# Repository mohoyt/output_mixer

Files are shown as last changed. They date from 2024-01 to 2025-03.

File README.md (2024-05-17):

# Output mixer for Eurorack

Inspired by the mixer in the Erica Synths x mki.edu line (but with added channels and SMD components)

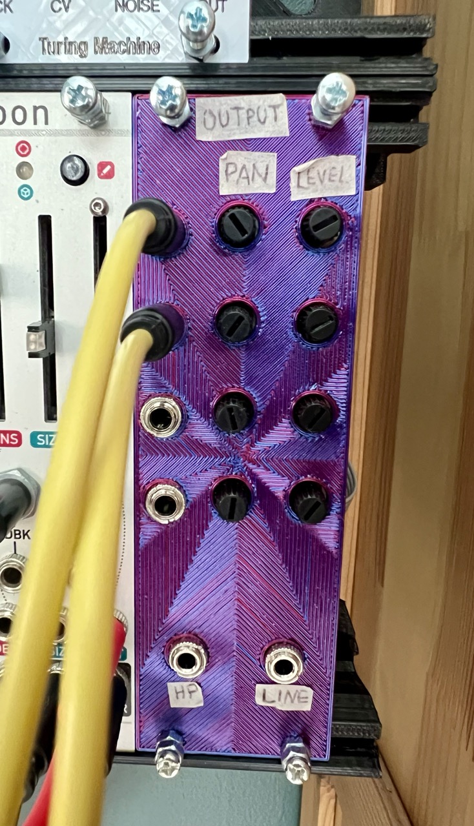
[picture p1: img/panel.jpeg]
Panel


## Features
- Eurorack format (3U panel height = 133.4mm)
- 8HP width (about 40mm)
- 4 inputs with pan (L-R) and level adjustable
- 2 outputs, line out and headphone out
- Mostly SMD with a couple through hole parts

## Issues
- [x] Pan is reversed
- [x] Not enough space for 1W 47R resistor
- [x] BD139/140 overheating

All addressed in current version (v1.1). The overheating was a result of poor quality BD139 and BD140 that I had sourced. 

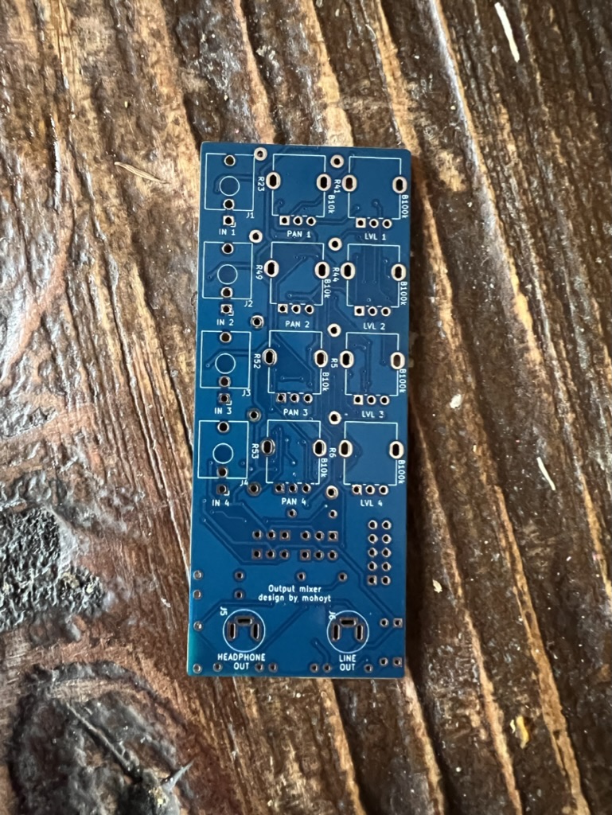
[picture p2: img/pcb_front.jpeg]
PCB front


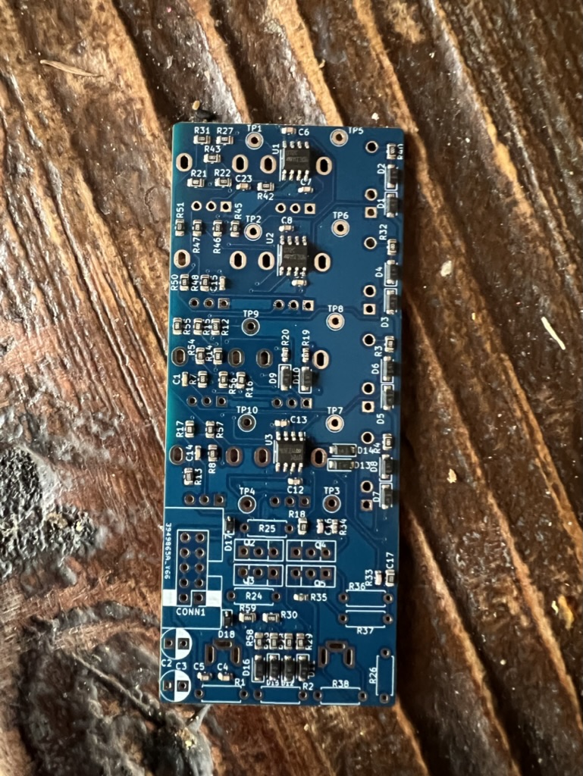
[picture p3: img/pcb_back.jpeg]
PCB back


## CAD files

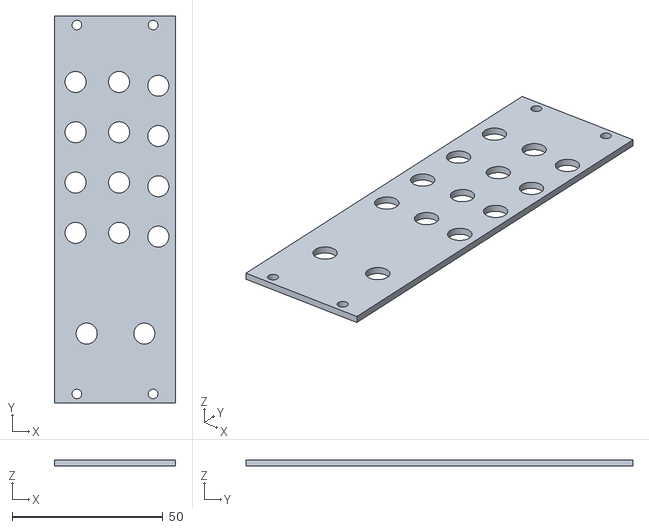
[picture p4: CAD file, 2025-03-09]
panel/Output Mixer.stl
40.3 x 128.5 x 2.00

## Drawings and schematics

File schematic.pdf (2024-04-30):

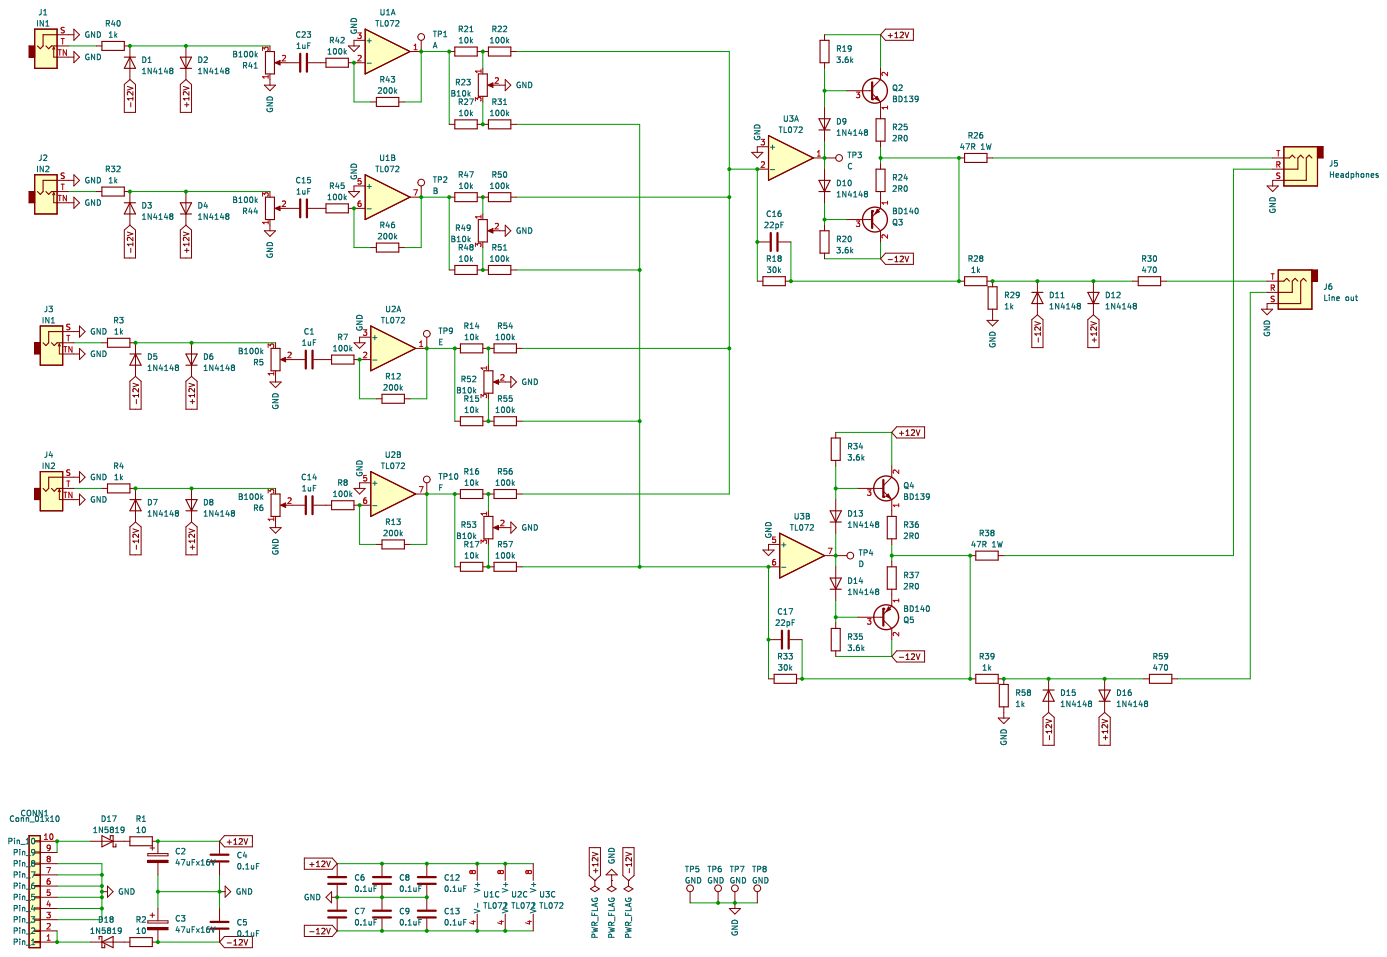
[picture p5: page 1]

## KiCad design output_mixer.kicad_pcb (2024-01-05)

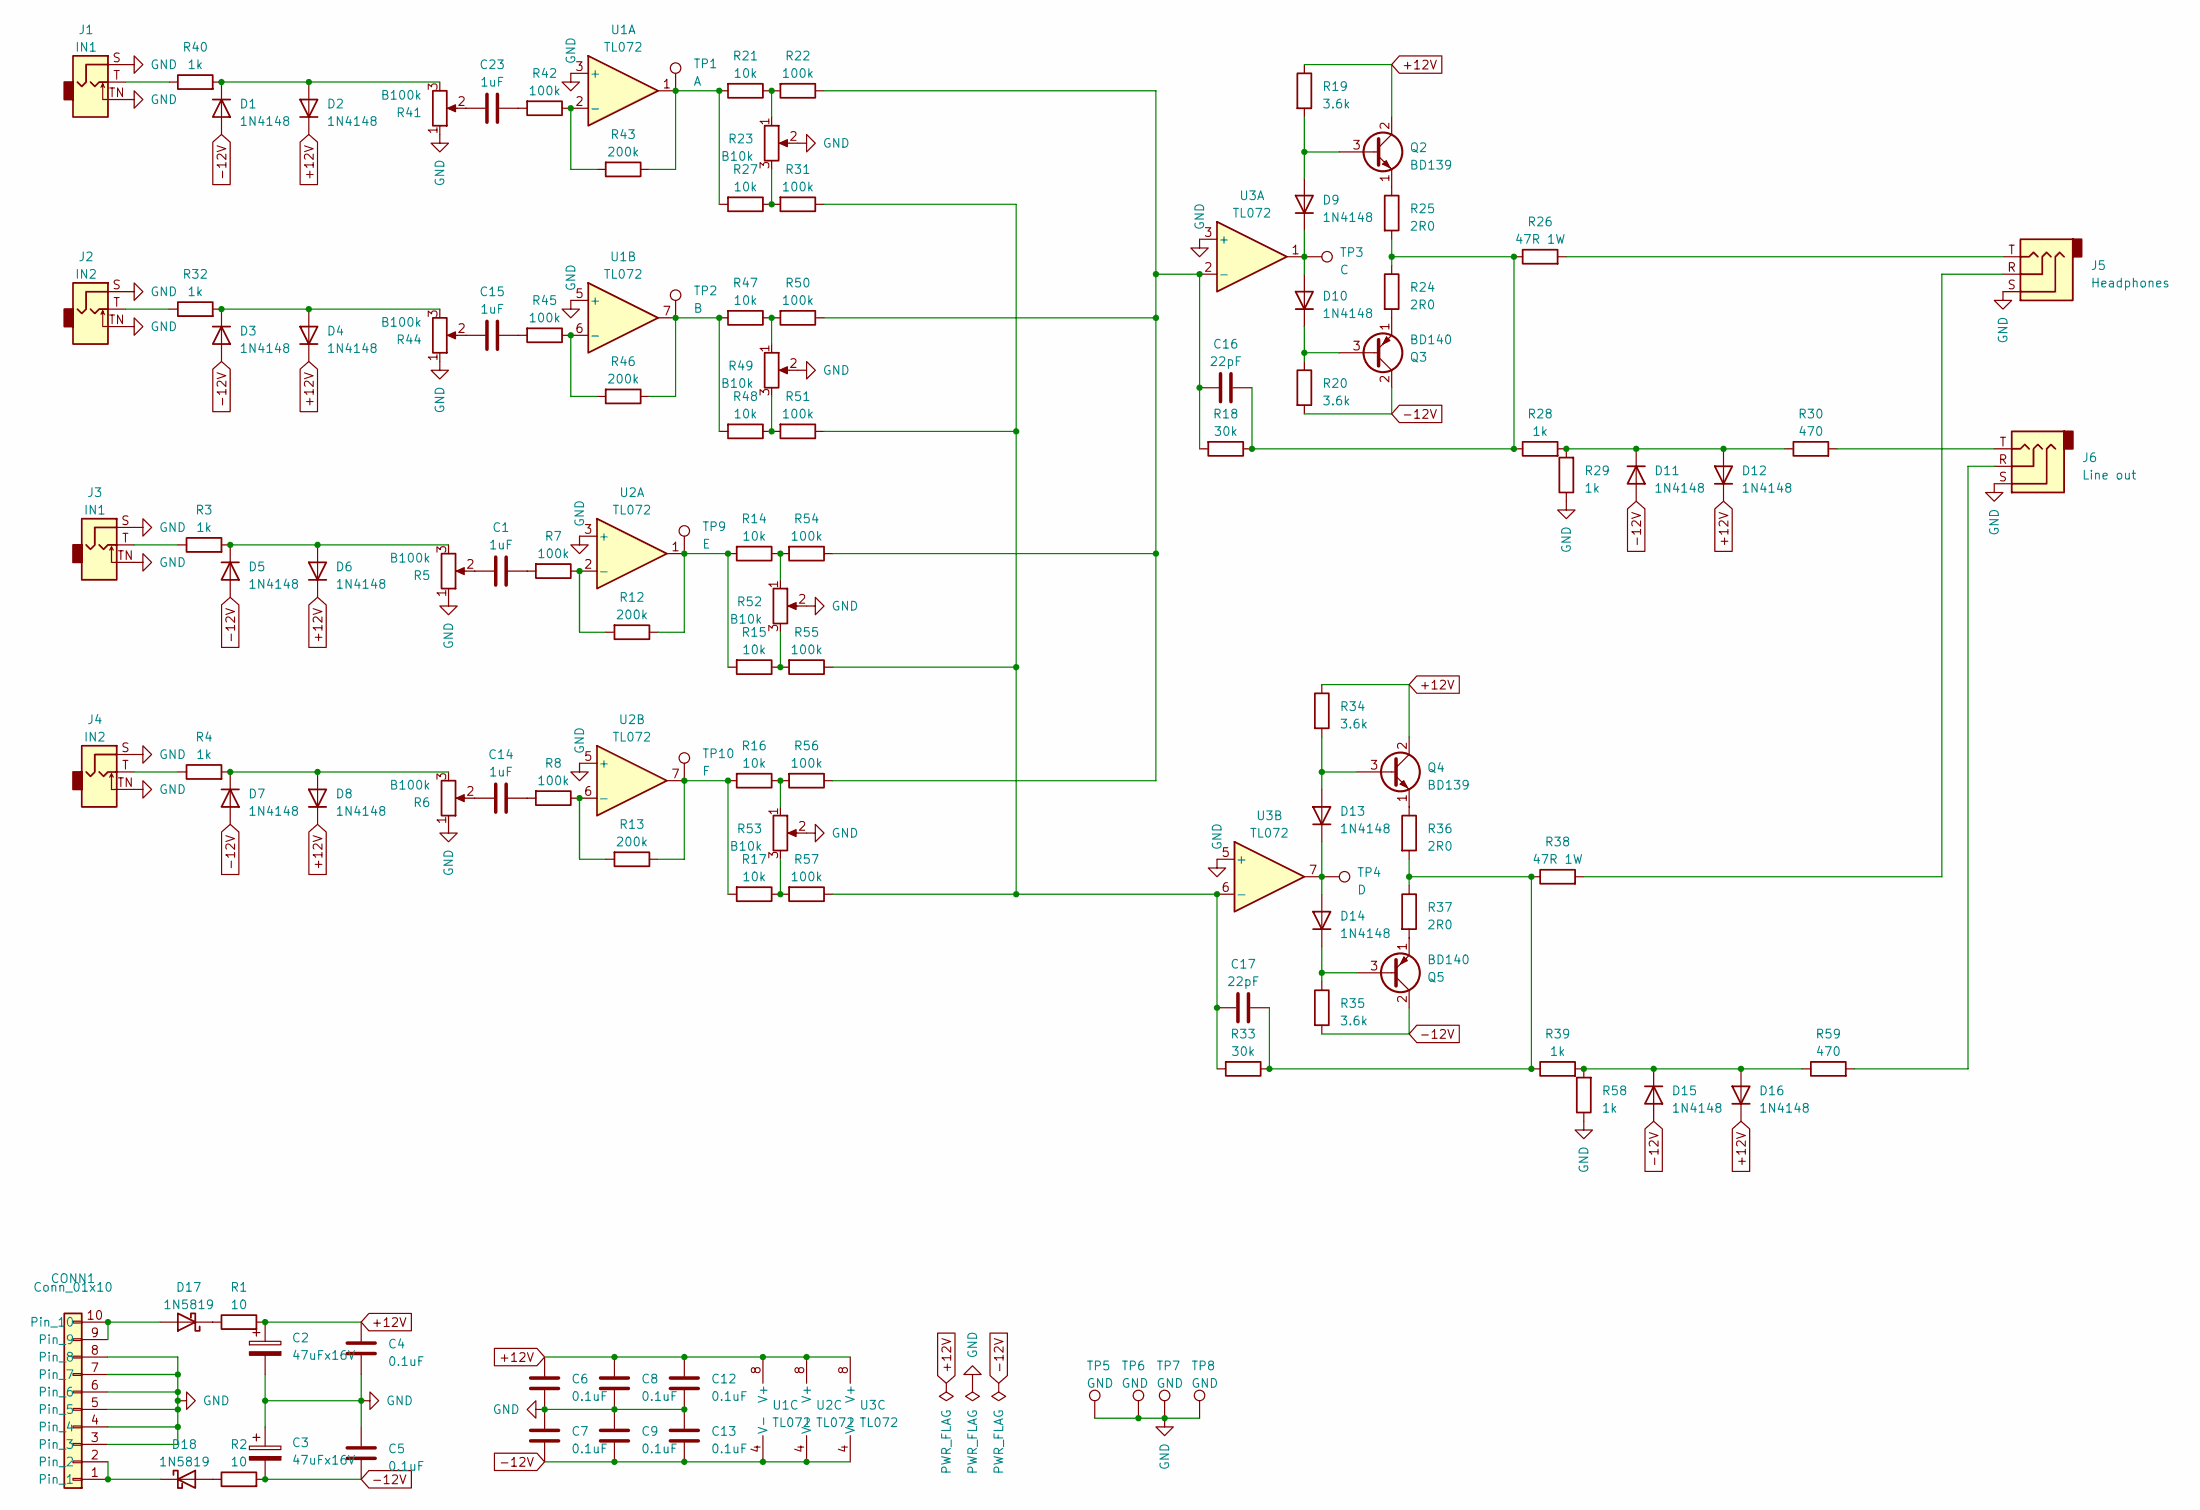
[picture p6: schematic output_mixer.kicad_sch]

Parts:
C1, C14, C15, C23: 1uF; C_0603_1608Metric; LCSC C15849
C2, C3: 47uFx16V; CP_Radial_D5.0mm_P2.50mm
C4, C5, C6, C7, C8, C9, C12, C13: 0.1uF; C_0603_1608Metric; LCSC C14663
C16, C17: 22pF; C_0603_1608Metric; LCSC C1653
CONN1: Conn_01x10; PinHeader_2x05_P2.54mm_Vertical_Shroud
D1, D2, D3, D4, D5, D6, D7, D8, D9, D10, D11, D12, D13, D14, D15, D16: 1N4148; D_SOD-123; LCSC C81598
D17, D18: 1N5819; D_SOD-323; LCSC C191023
J1, J3: IN1; Jack_3.5mm_QingPu_WQP-PJ398SM_Vertical_CircularHoles
J2, J4: IN2; Jack_3.5mm_QingPu_WQP-PJ398SM_Vertical_CircularHoles
J5: Headphones; Jack_3.5mm_Stereo_Unbranded
J6: Line out; Jack_3.5mm_Stereo_Unbranded
Q2, Q4: BD139; TO-126-3_Vertical
Q3, Q5: BD140; TO-126-3_Vertical
R1, R2: 10; R_Axial_DIN0207_L6.3mm_D2.5mm_P7.62mm_Horizontal
R3, R4, R28, R29, R32, R39, R40, R58: 1k; R_0805_2012Metric; LCSC C17513
R5, R6, R41, R44: B100k; Potentiometer_Alpha_RD901F-40-00D_Single_Vertical
R7, R8, R22, R31, R42, R45, R50, R51, R54, R55, R56, R57: 100k; R_0805_2012Metric; LCSC C149504
R12, R13, R43, R46: 200k; R_0805_2012Metric; LCSC C17539
R14, R15, R16, R17, R21, R27, R47, R48: 10k; R_0805_2012Metric; LCSC C17414
R18, R33: 30k; R_0805_2012Metric; LCSC C17621
R19, R20, R34, R35: 3.6k; R_0603_1608Metric; LCSC C22980
R23, R49, R52, R53: B10k; Potentiometer_Alpha_RD901F-40-00D_Single_Vertical
R24, R25, R36, R37: 2R0; R_Axial_DIN0207_L6.3mm_D2.5mm_P7.62mm_Horizontal
R26, R38: 47R 1W; R_Axial_DIN0309_L9.0mm_D3.2mm_P12.70mm_Horizontal
R30, R59: 470; R_0805_2012Metric; LCSC C17710
TP1: A; TestPoint_THTPad_D2.5mm_Drill1.2mm
TP2: B; TestPoint_THTPad_D2.5mm_Drill1.2mm
TP3: C; TestPoint_THTPad_D2.5mm_Drill1.2mm
TP4: D; TestPoint_THTPad_D2.5mm_Drill1.2mm
TP5, TP6, TP7, TP8: GND; TestPoint_THTPad_D2.5mm_Drill1.2mm
TP9: E; TestPoint_THTPad_D2.5mm_Drill1.2mm
TP10: F; TestPoint_THTPad_D2.5mm_Drill1.2mm
U1, U2, U3: TL072; SOP-8_3.9x4.9mm_P1.27mm; LCSC C6961

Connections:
+12V: C2.1, C4.1, C6.1, C8.1, C12.1, D2.1 (K), D4.1 (K), D6.1 (K), D8.1 (K), D12.1 (K), D16.1 (K), Q2.2 (C), Q4.2 (C), R1.2, R19.1, R34.1, U1.8 (V+), U2.8 (V+), U3.8 (V+)
-12V: C3.2, C5.2, C7.2, C9.2, C13.2, D1.2 (A), D3.2 (A), D5.2 (A), D7.2 (A), D11.2 (A), D15.2 (A), Q3.2 (C), Q5.2 (C), R2.2, R20.2, R35.2, U1.4 (V-), U2.4 (V-), U3.4 (V-)
GND: C2.2, C3.1, C4.2, C5.1, C6.2, C7.1, C8.2, C9.1, C12.2, C13.1, CONN1.3, CONN1.4, CONN1.5, CONN1.6, CONN1.7, CONN1.8, J1.S, J1.TN, J2.S, J2.TN, J3.S, J3.TN, J4.S, J4.TN, J5.S, J6.S, R5.1, R6.1, R23.2, R29.1, R41.1, R44.1, R49.2, R52.2, R53.2, R58.1, TP5.1, TP6.1, TP7.1, TP8.1, U1.3 (+), U1.5 (+), U2.3 (+), U2.5 (+), U3.3 (+), U3.5 (+)
unnamed: C1.1, R5.2
unnamed: C1.2, R7.2
unnamed: C14.1, R6.2
unnamed: C14.2, R8.2
unnamed: C15.1, R44.2
unnamed: C15.2, R45.2
unnamed: C16.2, R18.1, R24.1, R25.2, R26.1, R28.1
unnamed: C17.2, R33.1, R36.2, R37.1, R38.1, R39.1
unnamed: C23.1, R41.2
unnamed: C23.2, R42.2
unnamed: CONN1.1, CONN1.2, D18.1 (K)
unnamed: CONN1.9, CONN1.10, D17.2 (A)
unnamed: D1.1 (K), D2.2 (A), R40.2, R41.3
unnamed: D3.1 (K), D4.2 (A), R32.2, R44.3
unnamed: D5.1 (K), D6.2 (A), R3.2, R5.3
unnamed: D7.1 (K), D8.2 (A), R4.2, R6.3
unnamed: D9.2 (A), Q2.3 (B), R19.2
unnamed: D9.1 (K), D10.2 (A), TP3.1, U3.1
unnamed: D10.1 (K), Q3.3 (B), R20.1
unnamed: D11.1 (K), D12.2 (A), R28.2, R29.2, R30.1
unnamed: D13.2 (A), Q4.3 (B), R34.2
unnamed: D13.1 (K), D14.2 (A), TP4.1, U3.7
unnamed: D14.1 (K), Q5.3 (B), R35.1
unnamed: D15.1 (K), D16.2 (A), R39.2, R58.2, R59.1
unnamed: D17.1 (K), R1.1
unnamed: D18.2 (A), R2.1
unnamed: J1.T, R40.1
unnamed: J2.T, R32.1
unnamed: J3.T, R3.1
unnamed: J4.T, R4.1
unnamed: J5.R, R38.2
unnamed: J5.T, R26.2
unnamed: J6.R, R59.2
unnamed: J6.T, R30.2
unnamed: Q2.1 (E), R25.1
unnamed: Q3.1 (E), R24.2
unnamed: Q4.1 (E), R36.1
unnamed: Q5.1 (E), R37.2
unnamed: R12.1, R14.2, R15.2, TP9.1, U2.1
unnamed: R13.1, R16.2, R17.2, TP10.1, U2.7
unnamed: R14.1, R52.1, R54.2
unnamed: R15.1, R52.3, R55.2
unnamed: R16.1, R53.1, R56.2
unnamed: R17.1, R53.3, R57.2
unnamed: R21.1, R22.2, R23.1
unnamed: R21.2, R27.2, R43.1, TP1.1, U1.1
unnamed: R23.3, R27.1, R31.2
unnamed: R46.1, R47.2, R48.2, TP2.1, U1.7
unnamed: R47.1, R49.1, R50.2
unnamed: R48.1, R49.3, R51.2
unnamed: R42.1, R43.2, U1.2 (-)
unnamed: R45.1, R46.2, U1.6 (-)
unnamed: R7.1, R12.2, U2.2 (-)
unnamed: R8.1, R13.2, U2.6 (-)
unnamed: C16.1, R18.2, R22.1, R50.1, R54.1, R56.1, U3.2 (-)
unnamed: C17.1, R31.1, R33.2, R51.1, R55.1, R57.1, U3.6 (-)

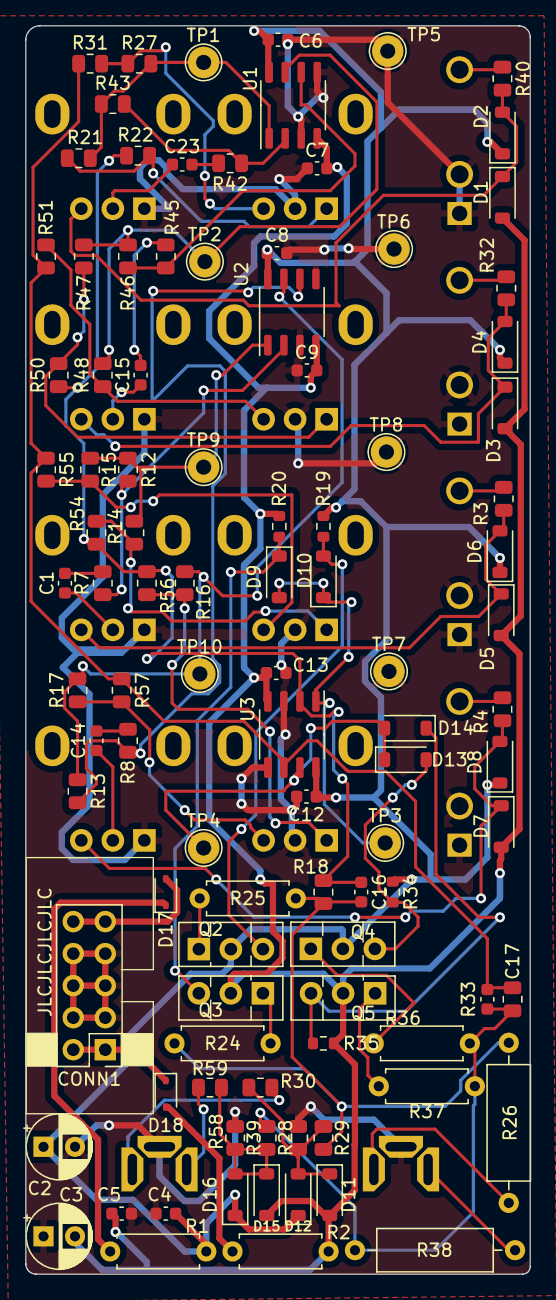
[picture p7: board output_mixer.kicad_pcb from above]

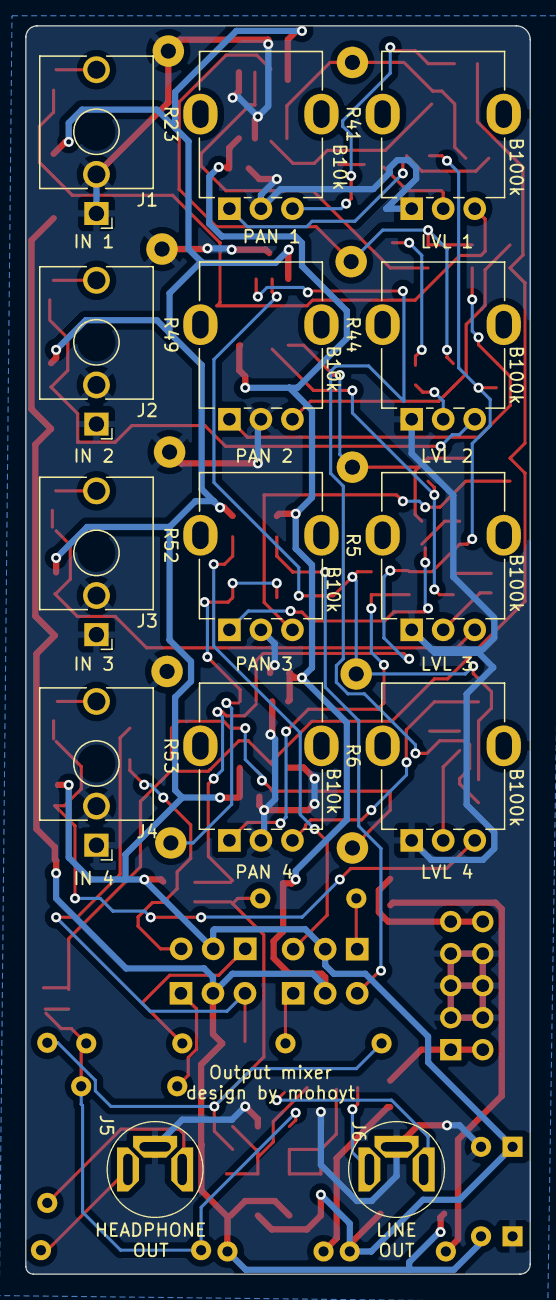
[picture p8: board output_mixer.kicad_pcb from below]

Board: 2 copper layers, 40.0 x 99.0 mm, 114 parts (14 on the bottom side), 59 nets.

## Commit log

2023-11-20 Schematic done
    [output_mixer.kicad_pcb, output_mixer.kicad_sch]
2023-11-21 schematic done, some parts added to PCB
    [output_mixer.kicad_pcb, output_mixer.kicad_sch]
2023-12-08 Design done and sent to production
    [output_mixer-CuBottom.gbr, output_mixer-CuTop.gbr, output_mixer-EdgeCuts.gbr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]
2024-01-05 BOM added
    [output_mixer.kicad_sch]
2024-01-05 v1 issues fixed (opposite panning and 47R resistor footprint size)
    [output_mixer-CuBottom.gbr, output_mixer-CuTop.gbr, output_mixer-EdgeCuts.gbr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]
2024-04-30 Schematic and license added
2025-03-09 Added panel stl
    [Output Mixer.stl]
